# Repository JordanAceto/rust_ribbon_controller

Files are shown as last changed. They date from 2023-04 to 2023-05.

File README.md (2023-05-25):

# Rust Language STM32L412 Ribbon Controller

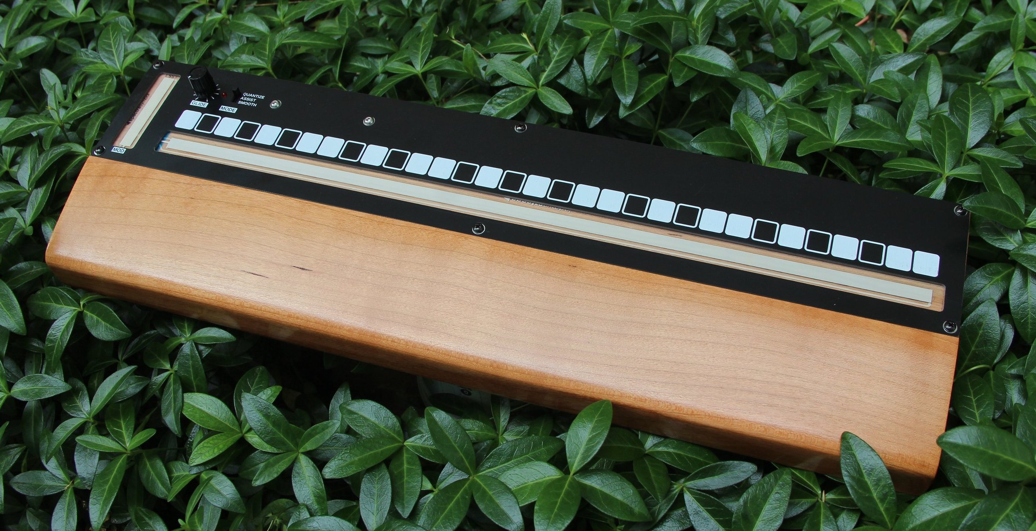
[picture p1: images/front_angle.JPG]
Photo of ribbon controller in nature


## Features

### Three analog outputs
- `RIBBON CV`: 1volt/per octave scaled control voltage generated by the main ribbon
- `GATE`: 5 volt gate signal which is high when pressing the main ribbon and low otherwise
- `MOD CV`: mod-wheel like control voltage generated by the MOD ribbon, in `[0v, +5v]` 

### MIDI output
- Note on/off based on finger position on the ribbon
- Pitch-bend message bends the pitch when the ribbon is in between notes 
- Mod: mod-wheel message generated by the MOD ribbon

### Three pitch modes are available
1) `QUANTIZE`: notes are forced to be musical half steps, sliding around will zipper to new notes
2) `ASSIST`: when you first press a new note it is forced to be a musical half step, but continued sliding is smooth
3) `SMOOTH`: no quantization is performed, offers the greatest degree of pitch freedom but is difficult to play in tune

### Glide control
- Adds portamento to the `RIBBON CV` signal
- This allows you to smooth out the steps when in `QUANTIZE` mode

### Notes about the MIDI output
- This software assumes that the pitch bend range on the receiving instrument is set to +/- 2 semitones (this is typically the default)
    - If the Assist or Smooth modes seem crazy, make sure that the pitch bend range on your instrument is set to +/- 2 semitones
- The MIDI output signal sends note-on, note-off, and pitch bend messages to generate the smooth ribbon action
    - This works best with a mono instrument, and may act differently depending on the MIDI implementation of the receiving device
    - If the receiving instrument has non-retriggering envelopes, it will smoothly slide as expected
    - If the instrument has retriggering envelopes, each time you slide into a new note the envelopes will be triggered
- The MIDI output starts on a fairly low note
    - It works best if the instrument being controlled can be transposed to different octaves

### Rear panel IO jacks and controls
- Output jacks for analog signals `RIBBON CV`, `MOD CV`, and `GATE`
- Standard `MIDI OUT` 5 pin DIN output jack
- `MIDI CH` channel select rotary switch
    - MIDI output is sent on the channel set here
- `9VDC IN` power supply input jack

rear panel render

## Calibration
- A trim potentiometer is exposed through a small hole so the device may be calibrated without disassembly
- Measure the `RIBBON CV` signal with a multimeter
- Set the `MODE` switch to `QUANTIZE`
- Adjust the trim potentiometer while playing alternating octaves so that the octaves are as close to 1.000v apart as you can get
- The `MOD CV` and MIDI output do not require calibration

## Power supply
- A common guitar-pedal style center-negative 9 volt DC wall wart powers the device
- The circuit consumes approximately 20mA from the 9 volt DC power supply

## Project status
- A prototype has been built and tested
- A handmade wooden body houses the components and provides a comfortable wrist rest while playing

## Project goals
- Mostly just for fun and to explore embedded Rust
- Serve as a test bed for the [Josh Ox Ribbon Synth](https://github.com/JordanAceto/josh_Ox_ribbon_synth)
- Build a cute little CV and MIDI source

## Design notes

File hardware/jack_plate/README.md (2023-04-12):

# jack_plate

## ribbon_controller_jack_plate

PCB front
PCB back

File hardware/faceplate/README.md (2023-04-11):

# faceplate

## ribbon_controller_faceplate

PCB front
PCB back

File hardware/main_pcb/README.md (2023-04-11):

# main_pcb

## ribbon_controller

PCB front
PCB back

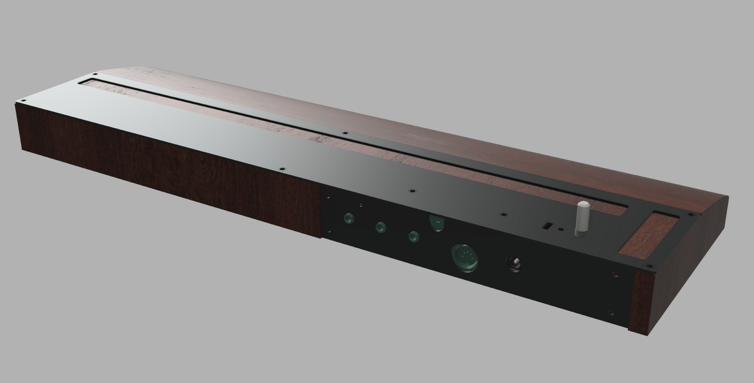
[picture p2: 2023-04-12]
images/rear_angle_render.png

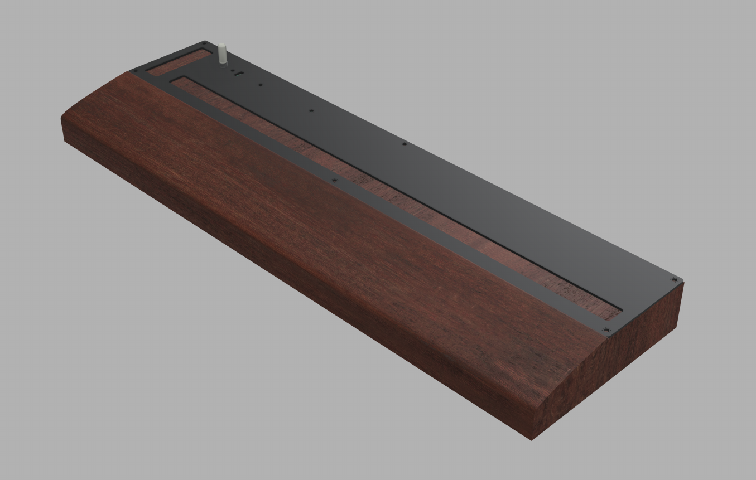
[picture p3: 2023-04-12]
images/front_angle_render.png

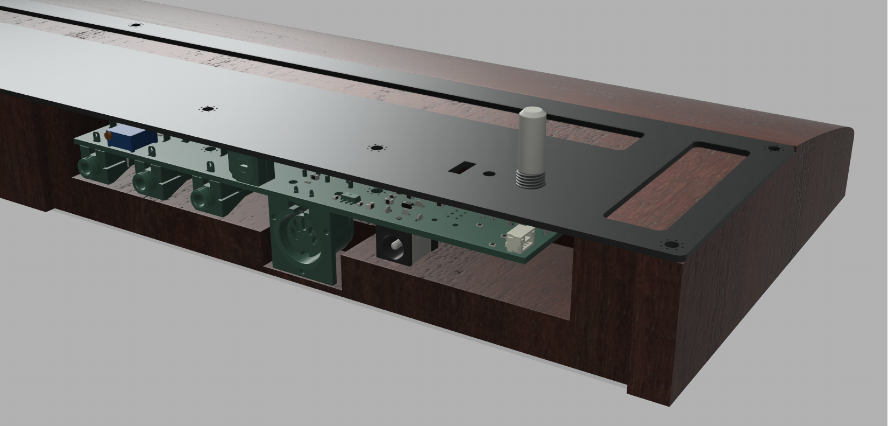
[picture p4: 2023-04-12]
images/pcb_detail_render.png

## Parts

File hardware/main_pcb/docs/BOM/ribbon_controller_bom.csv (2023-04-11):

# | Reference | Qty | Value | Footprint | DNP
1 | C201, C301, C307, C309, C311, C312, C501, C502, C503, C504, C505, C506, C507, C602, C603, C605 | 16 | 100n | Capacitor_SMD:C_0603_1608Metric
2 | C302, C304 | 2 | 4p3 | Capacitor_SMD:C_0603_1608Metric
3 | C303 | 1 | 10u | Capacitor_SMD:C_0805_2012Metric
4 | C305, C306, C308, C310 | 4 | 1u | Capacitor_SMD:C_0805_2012Metric
5 | C601, C604 | 2 | 2u2 | Capacitor_SMD:C_0805_2012Metric
6 | D601 | 1 | XLMDK65D | LED_THT:LED_D3.0mm
7 | D602 | 1 | B5819W | Diode_SMD:D_SOD-123
8 | FB501, FB502 | 2 | 600R @ 100MHz | Inductor_SMD:L_0805_2012Metric
9 | FB601, FB602, FB603 | 3 | 100R @ 100MHz | Inductor_SMD:L_0805_2012Metric
10 | H601, H602 | 2 | MountingHole_Pad | MountingHole:MountingHole_3.2mm_M3_Pad_Via
11 | J101, J102, J103 | 3 | PJ302M | custom_footprints:PJ302M
12 | J104 | 1 | CUI_SDF-50J | custom_footprints:CUI_SDF-50J
13 | J301 | 1 | SWD_header | Connector_PinHeader_2.54mm:PinHeader_1x04_P2.54mm_Vertical
14 | J601 | 1 | CUI_PJ-063AH | Connector_BarrelJack:BarrelJack_CUI_PJ-063AH_Horizontal
15 | R201, R202, R301, R501, R502, R504, R505, R506, R601 | 9 | 10k | Resistor_SMD:R_0603_1608Metric
16 | R203, R204 | 2 | 1M | Resistor_SMD:R_0603_1608Metric
17 | R302, R507, R510, R511 | 4 | 220 | Resistor_SMD:R_0603_1608Metric
18 | R503 | 1 | 9k1 | Resistor_SMD:R_0603_1608Metric
19 | R508, R509 | 2 | 1k | Resistor_SMD:R_0603_1608Metric
20 | RV301 | 1 | 10k | custom_footprints:Potentiometer_Alpha_RD901F-40-00D_Single_Vertical
21 | RV501 | 1 | 2k | custom_footprints:Potentiometer_Bourns_3296P_Horizontal
22 | SP1 | 1 | 400mm_softpot | Connector_JST:JST_GH_SM03B-GHS-TB_1x03-1MP_P1.25mm_Horizontal
23 | SP2 | 1 | 50mm_softpot | Connector_JST:JST_GH_SM03B-GHS-TB_1x03-1MP_P1.25mm_Horizontal
24 | SW301 | 1 | E-Switch_EG2301 | custom_footprints:E-Switch_EG2301
25 | SW302 | 1 | nidec_SD-1011 | custom_footprints:SD-1011
26 | TP401 | 1 | ~{CLR} | TestPoint:TestPoint_Pad_1.5x1.5mm
27 | TP601 | 1 | GND | TestPoint:TestPoint_Bridge_Pitch7.62mm_Drill1.3mm
28 | U1, U4 | 2 | MCP6002-xSN | Package_SO:SO-8_3.9x4.9mm_P1.27mm
29 | U2 | 1 | STM32L412K8Ux | Package_DFN_QFN:QFN-32-1EP_5x5mm_P0.5mm_EP3.45x3.45mm
30 | U3 | 1 | DAC8162xDGSx | Package_SO:VSSOP-10_3x3mm_P0.5mm
31 | U5, U6 | 2 | SN74LV1T34DBV | Package_TO_SOT_SMD:SOT-23-5
32 | U601 | 1 | L78L05_SOT89 | Package_TO_SOT_SMD:SOT-89-3
33 | U602 | 1 | L78L33_SOT89 | Package_TO_SOT_SMD:SOT-89-3
34 | Y1 | 1 | 32_768KHZ | Crystal:Crystal_SMD_MicroCrystal_CC7V-T1A-2Pin_3.2x1.5mm

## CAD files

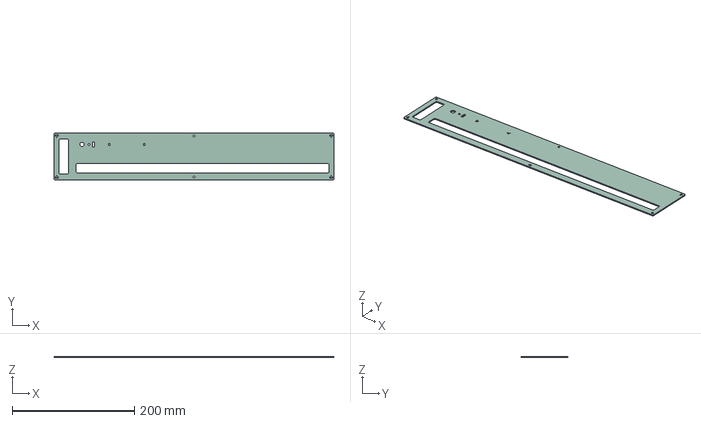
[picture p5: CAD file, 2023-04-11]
hardware/faceplate/docs/3D/ribbon_controller_faceplate.step
457.2 x 76.2 x 1.58 mm

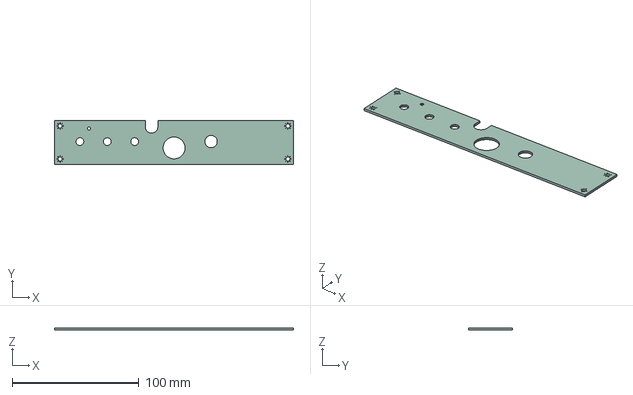
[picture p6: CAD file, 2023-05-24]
hardware/jack_plate/docs/3D/ribbon_controller_jack_plate.step
188.6 x 34.9 x 1.58 mm

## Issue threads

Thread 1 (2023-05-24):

Front panel main ribbon cutout is slightly too long

JordanAceto, 2023-05-24:
The front panel is made of 1.6mm PCB material. There is screen printing to show the notes piano-style, and a cutout so your finger can press on the actual ribbon.

The cutout is just slightly longer than it needs to be. This makes it so if you jam your finger to the very ends, you run off the ribbon and the note you were playing dies or rapidly toggles between on and off.

This isn't a show stopping problem. The user can easily adapt by not moving their finger so far, and it only happens when you play the notes at the extreme ends. But it should be fixed.

The next revision of the front panel should slightly reduce the horizontal span on the main ribbon cutout.

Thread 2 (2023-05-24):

It's hard to cleanly hit the ends of the MODWHEEL ribbon

JordanAceto, 2023-05-24:
When playing the shorter auxiliary MODWHEEL ribbon, it is hard to set your finger on the lowest and highest points and have it stay there. Any slight rolling of your finger bumps the output.

This is mostly noticeable when you have some modulation signal providing vibrato, and you try to turn it all the way down with the MODWHEEL ribbon. It's easy to roll your finger unintentionally and turn the vibrato back on slightly.

To fix, overdrive and clamp the MODWHEEL ribbon so that there are small deadzones at the top and bottom ends. This way, you just need to be near the end, and a small unavoidable finger roll won't throw off the output.

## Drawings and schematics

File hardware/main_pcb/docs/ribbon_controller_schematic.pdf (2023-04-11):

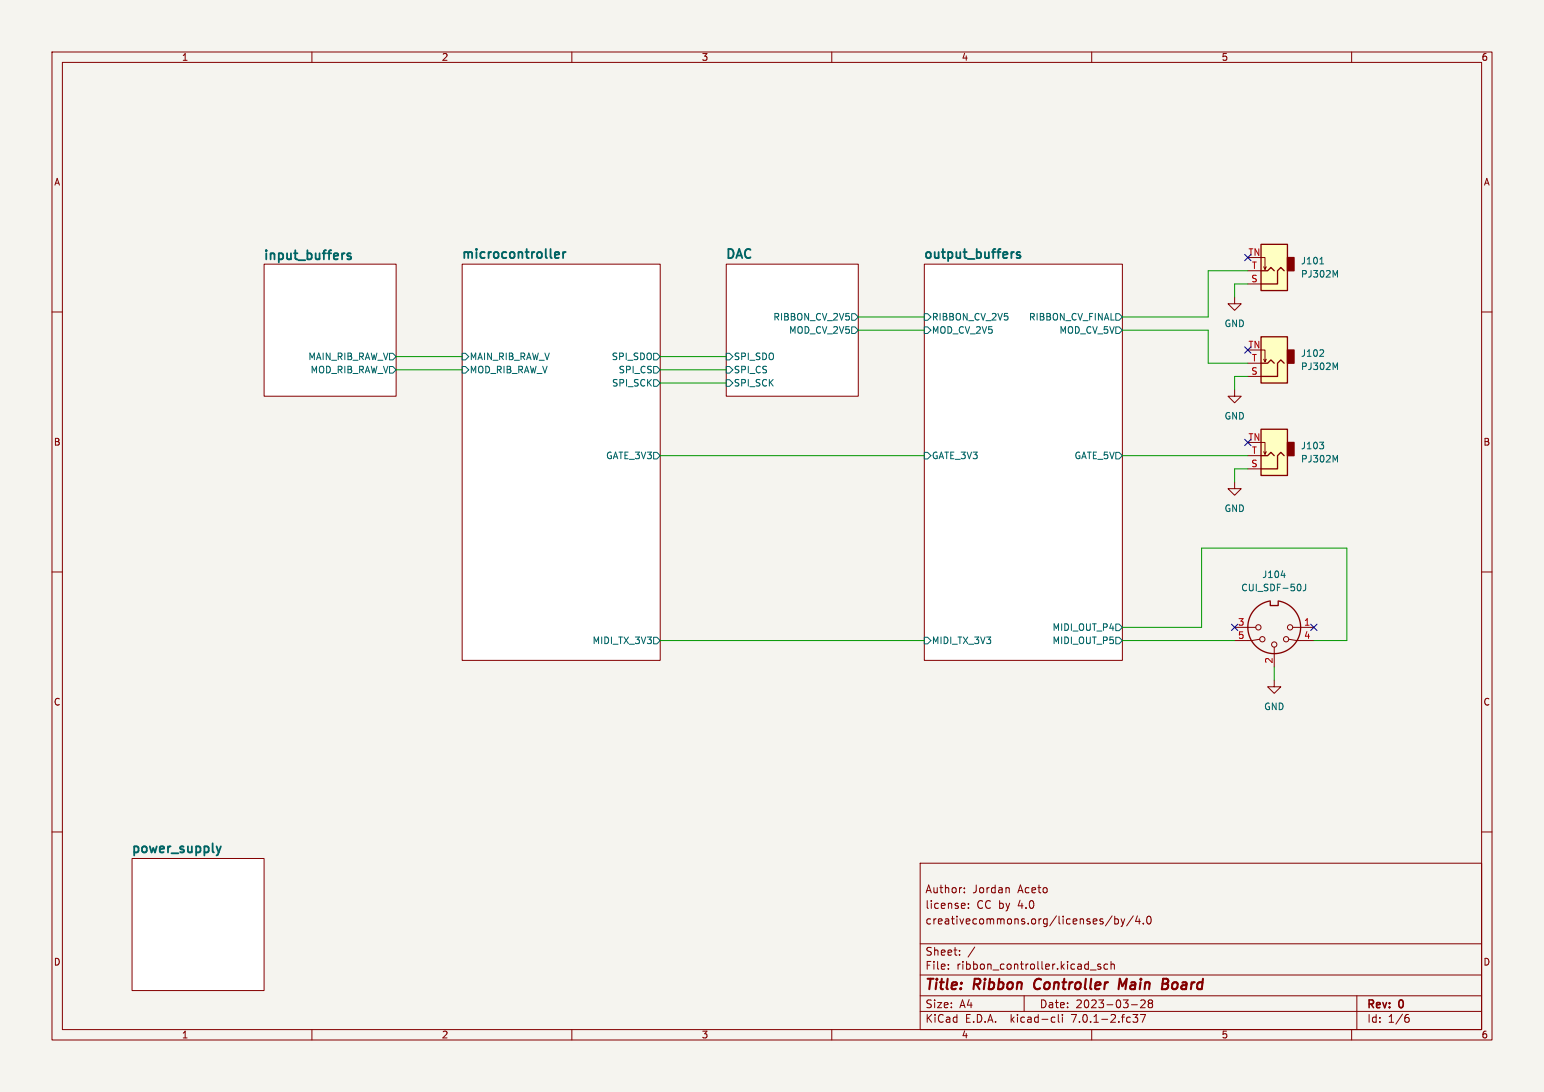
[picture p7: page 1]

File: ribbon_controller.kicad_sch Sheet: / creativecommons.org/licenses/by/4.0

Id: 1/6 Title: Ribbon Controller Main Board

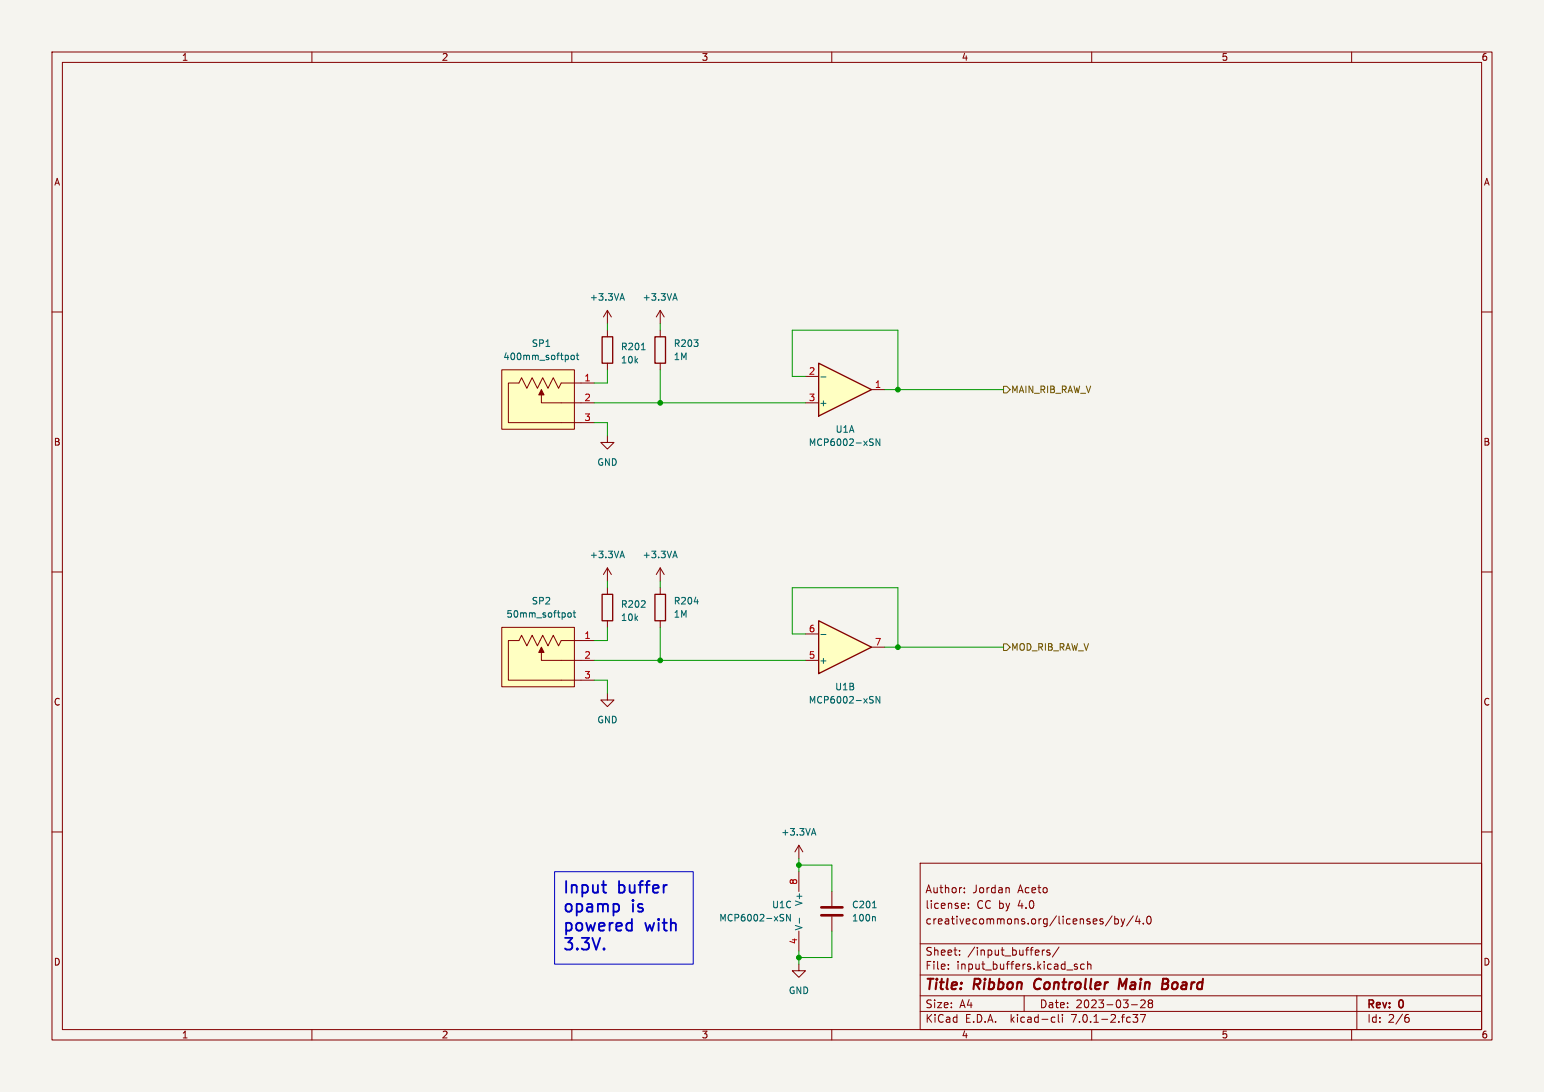
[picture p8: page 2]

creativecommons.org/licenses/by/4.0

File: input_buffers.kicad_sch Sheet: /input_buffers/
Id: 2/6 Title: Ribbon Controller Main Board

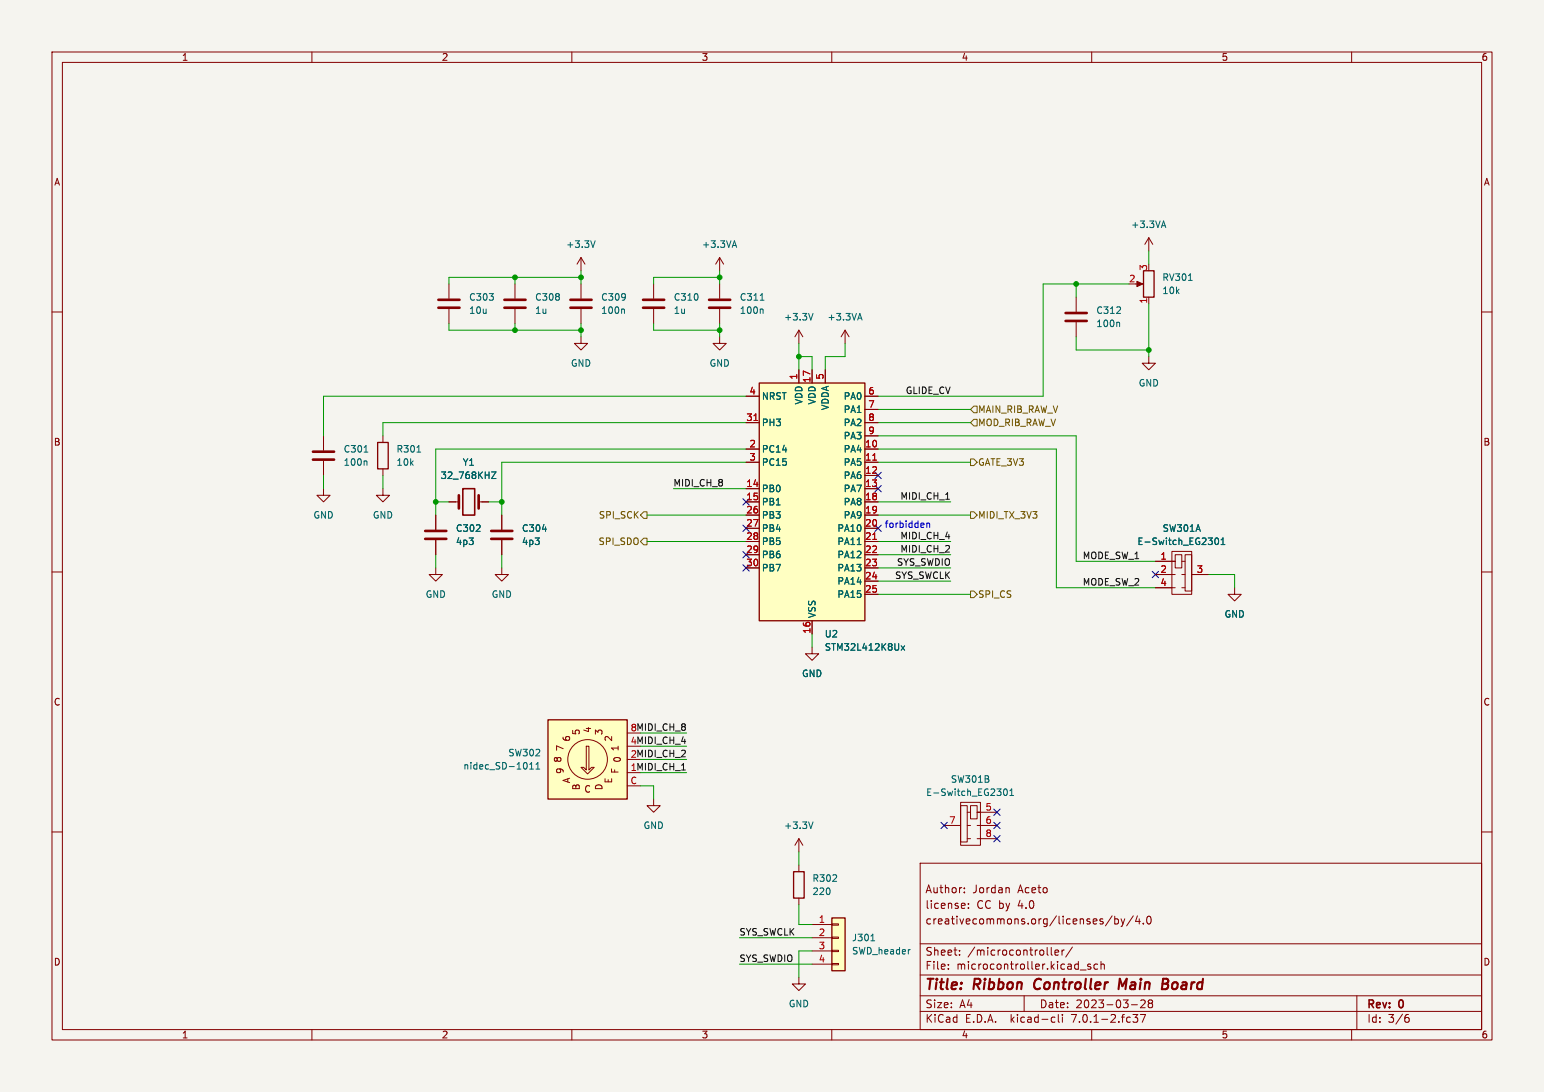
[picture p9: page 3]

1 PA4 10 PA5 11 PA6 12 PA7 13 PB0 14 PB1 15 VSS 16 VDD 17 PA8 18 PA9 19 PC14 2 PA10 20 PA11 21 PA12 22 PA13 23 PA14 24 PA15 25 PB3 26 PB4 27 PB5 28 PB6 29 PC15 3 PB7 30 PH3 31 NRST 4 VDDA

File: microcontroller.kicad_sch Sheet: /microcontroller/ creativecommons.org/licenses/by/4.0

Id: 3/6 Title: Ribbon Controller Main Board

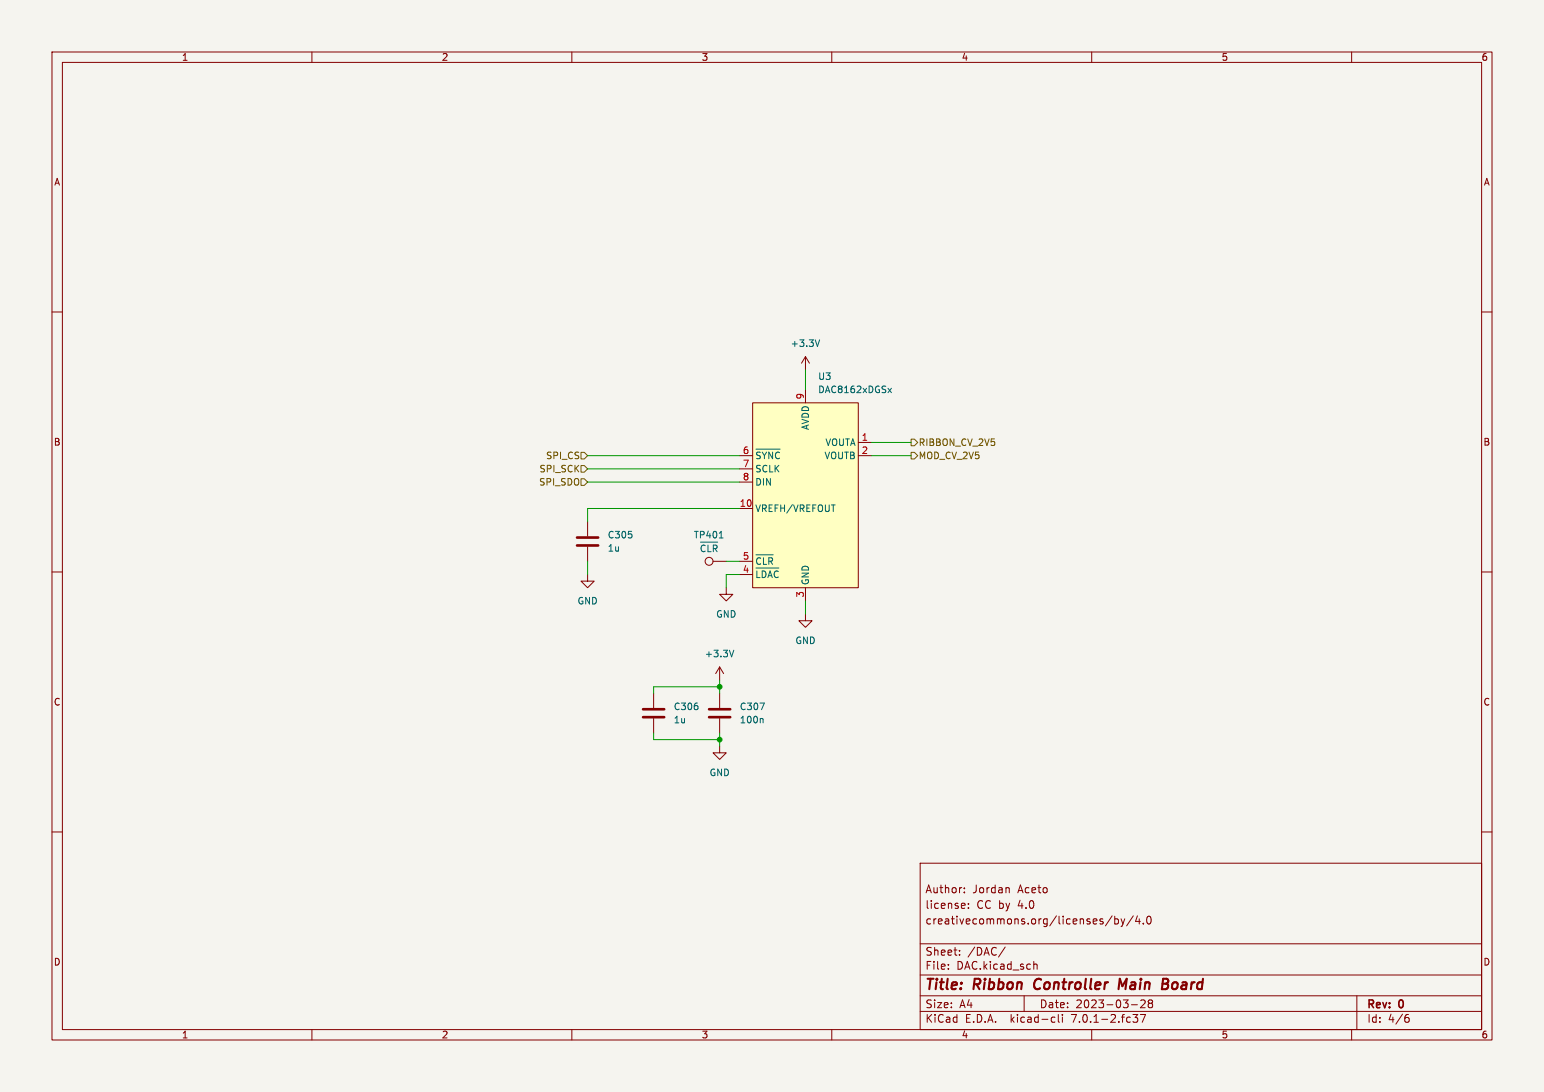
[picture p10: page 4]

3 ~{LDAC} 4 ~{CLR} 5 ~{SYNC} 6 SCLK 7 DIN 8 AVDD

Id: 4/6 Title: Ribbon Controller Main Board

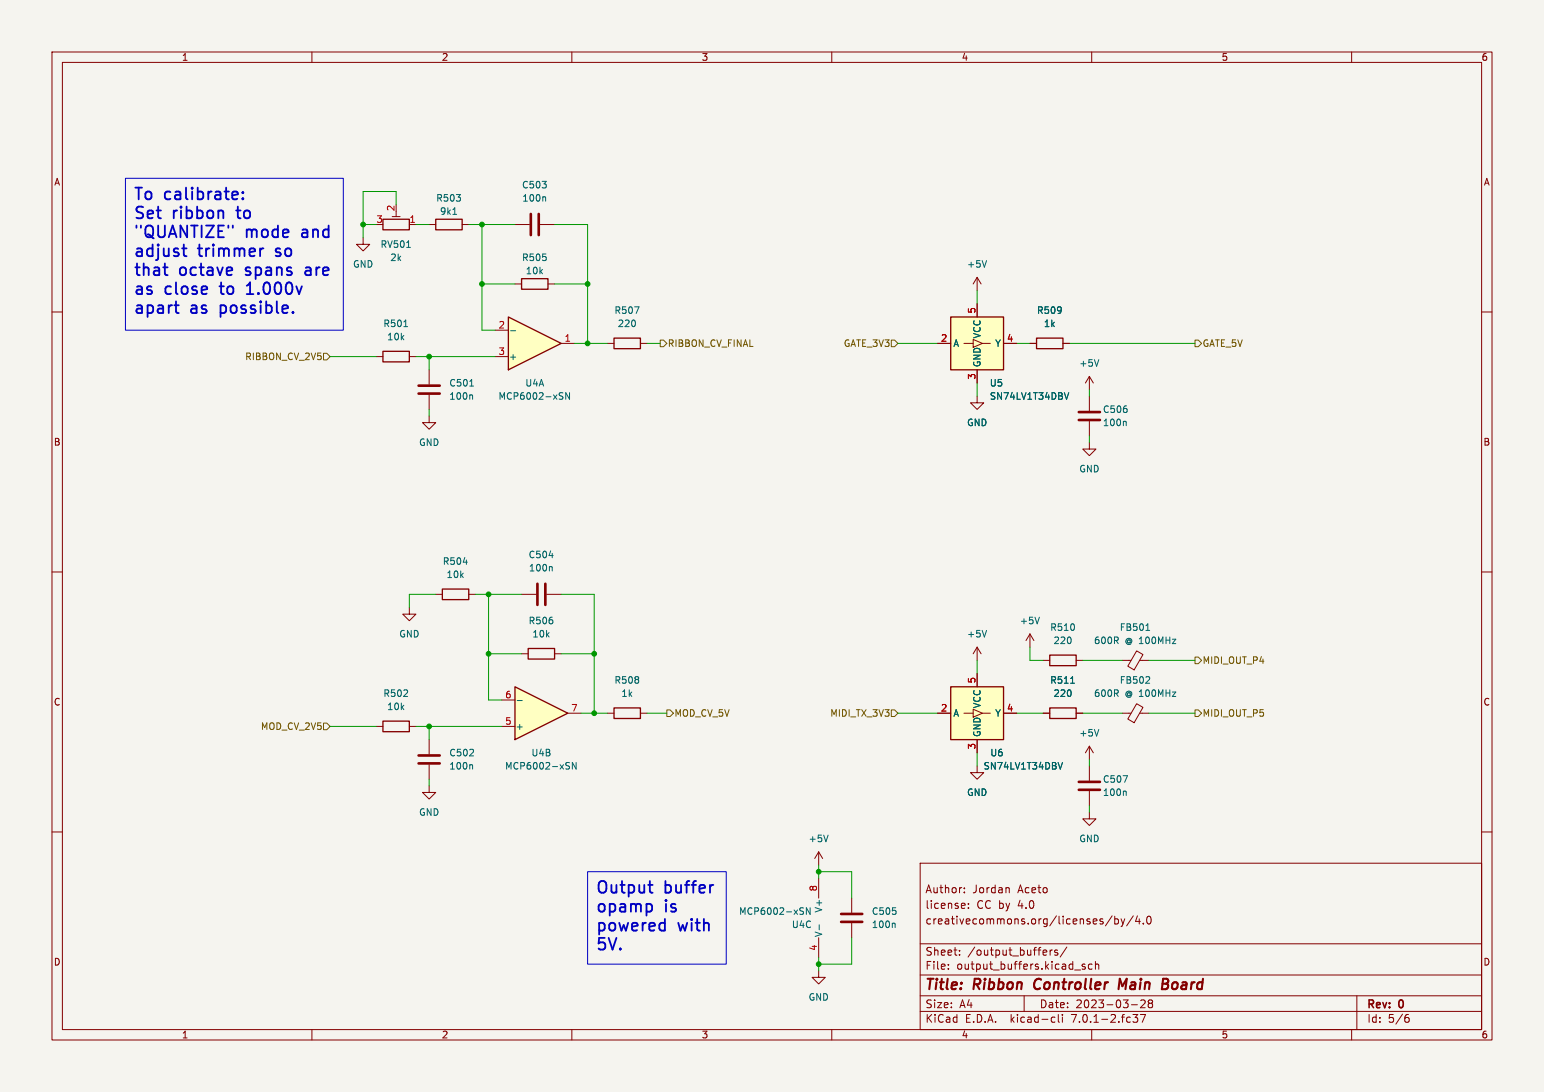
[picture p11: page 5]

To calibrate:
Set ribbon to
"QUANTIZE" mode and
adjust trimmer so
that octave spans are
as close to 1.000v

creativecommons.org/licenses/by/4.0

File: output_buffers.kicad_sch Sheet: /output_buffers/
Id: 5/6 Title: Ribbon Controller Main Board

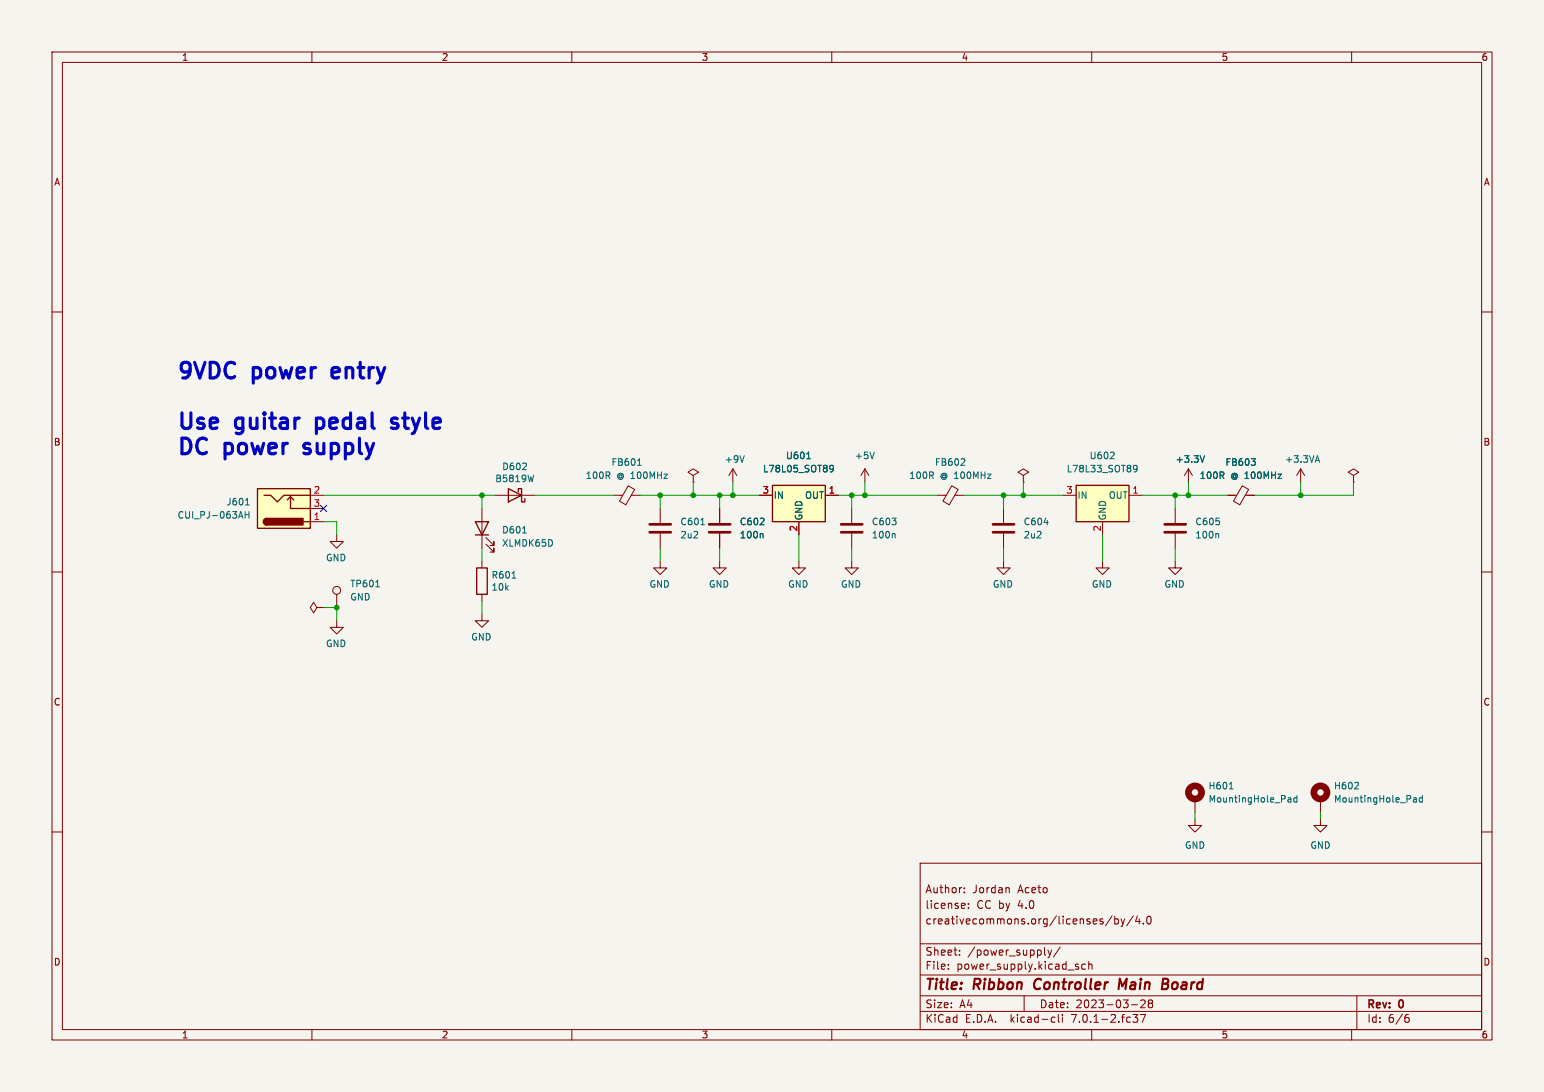
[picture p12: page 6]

creativecommons.org/licenses/by/4.0

Id: 6/6 Title: Ribbon Controller Main Board

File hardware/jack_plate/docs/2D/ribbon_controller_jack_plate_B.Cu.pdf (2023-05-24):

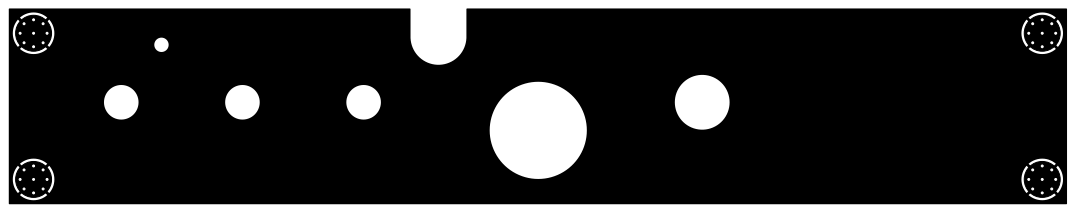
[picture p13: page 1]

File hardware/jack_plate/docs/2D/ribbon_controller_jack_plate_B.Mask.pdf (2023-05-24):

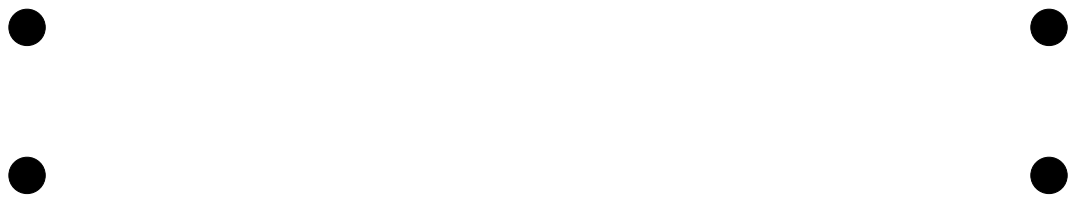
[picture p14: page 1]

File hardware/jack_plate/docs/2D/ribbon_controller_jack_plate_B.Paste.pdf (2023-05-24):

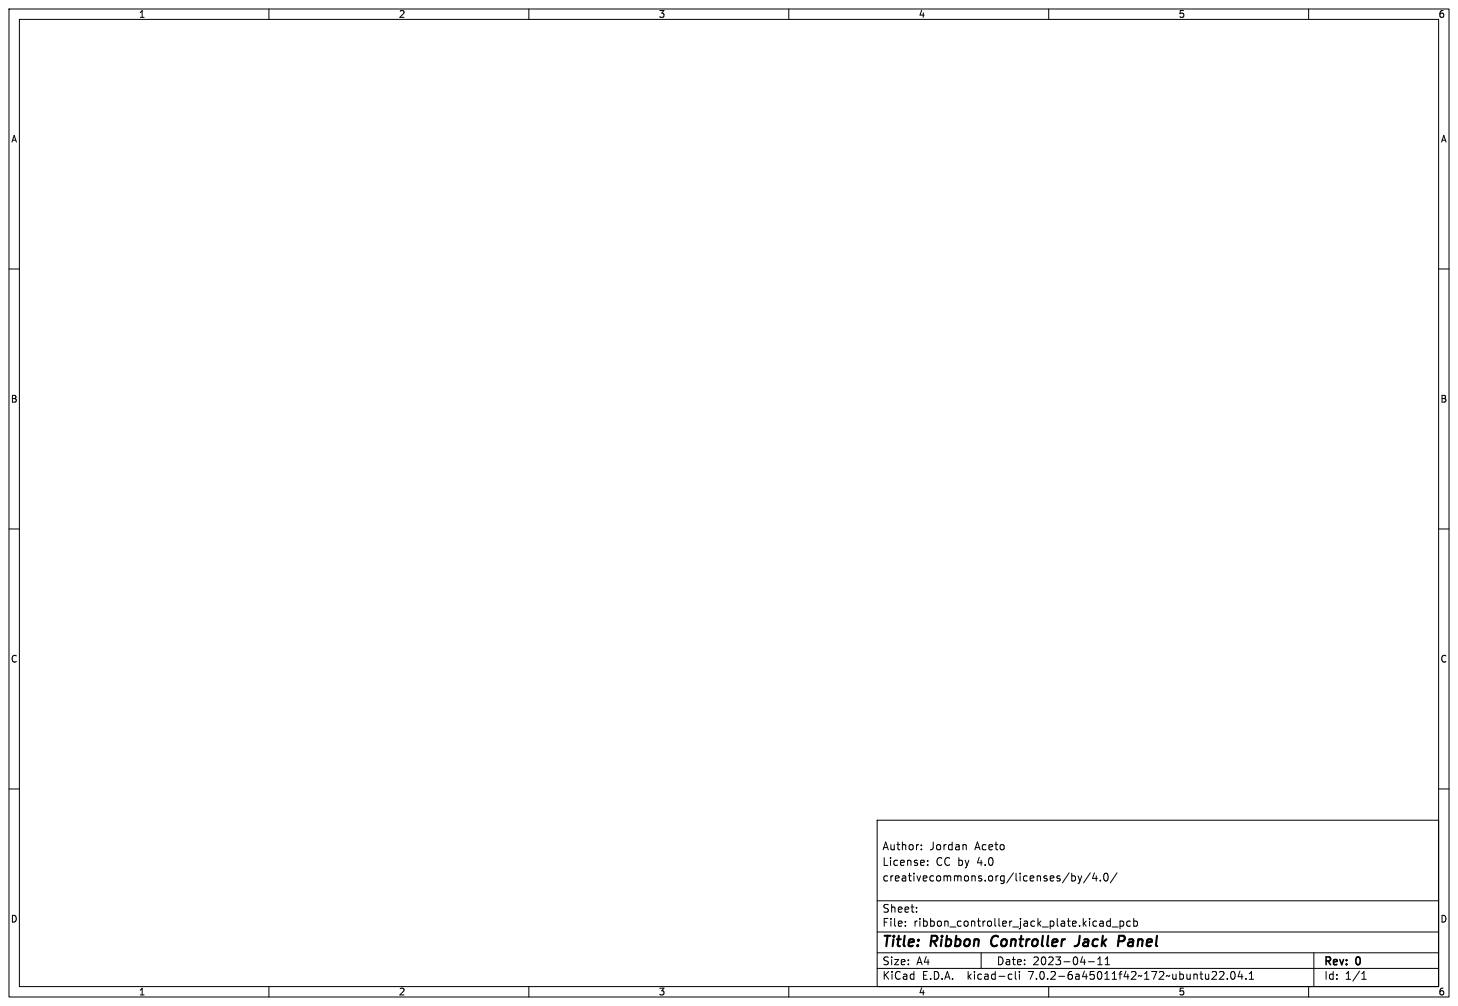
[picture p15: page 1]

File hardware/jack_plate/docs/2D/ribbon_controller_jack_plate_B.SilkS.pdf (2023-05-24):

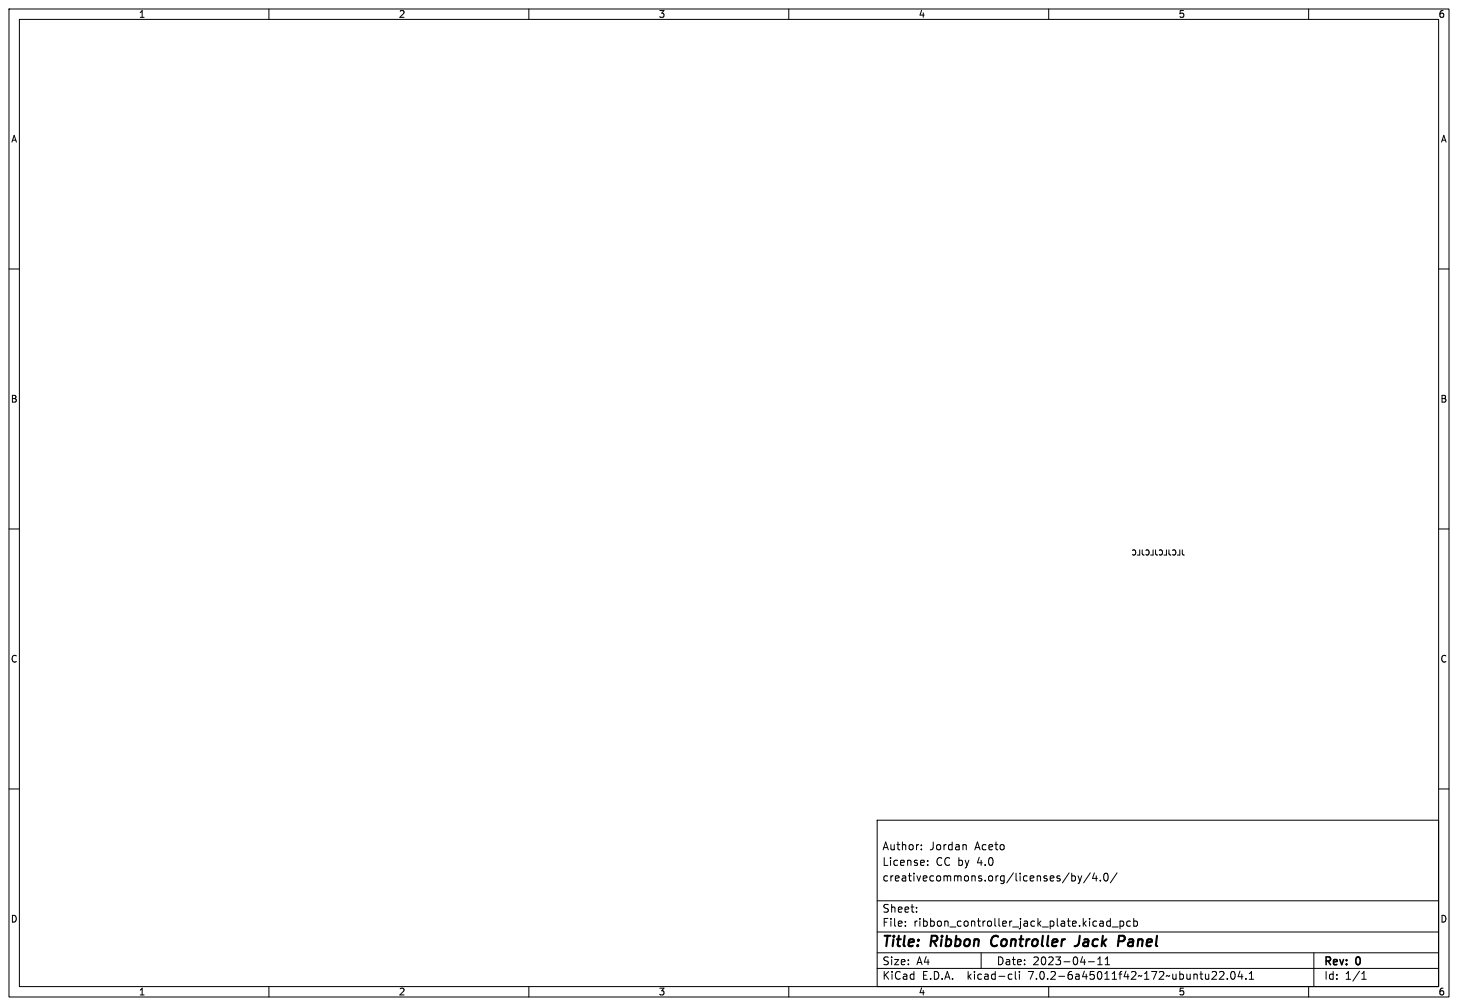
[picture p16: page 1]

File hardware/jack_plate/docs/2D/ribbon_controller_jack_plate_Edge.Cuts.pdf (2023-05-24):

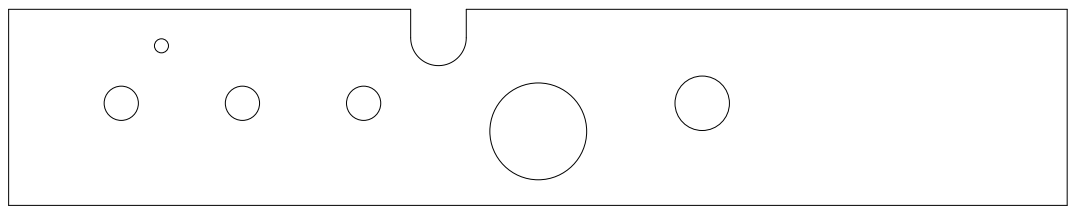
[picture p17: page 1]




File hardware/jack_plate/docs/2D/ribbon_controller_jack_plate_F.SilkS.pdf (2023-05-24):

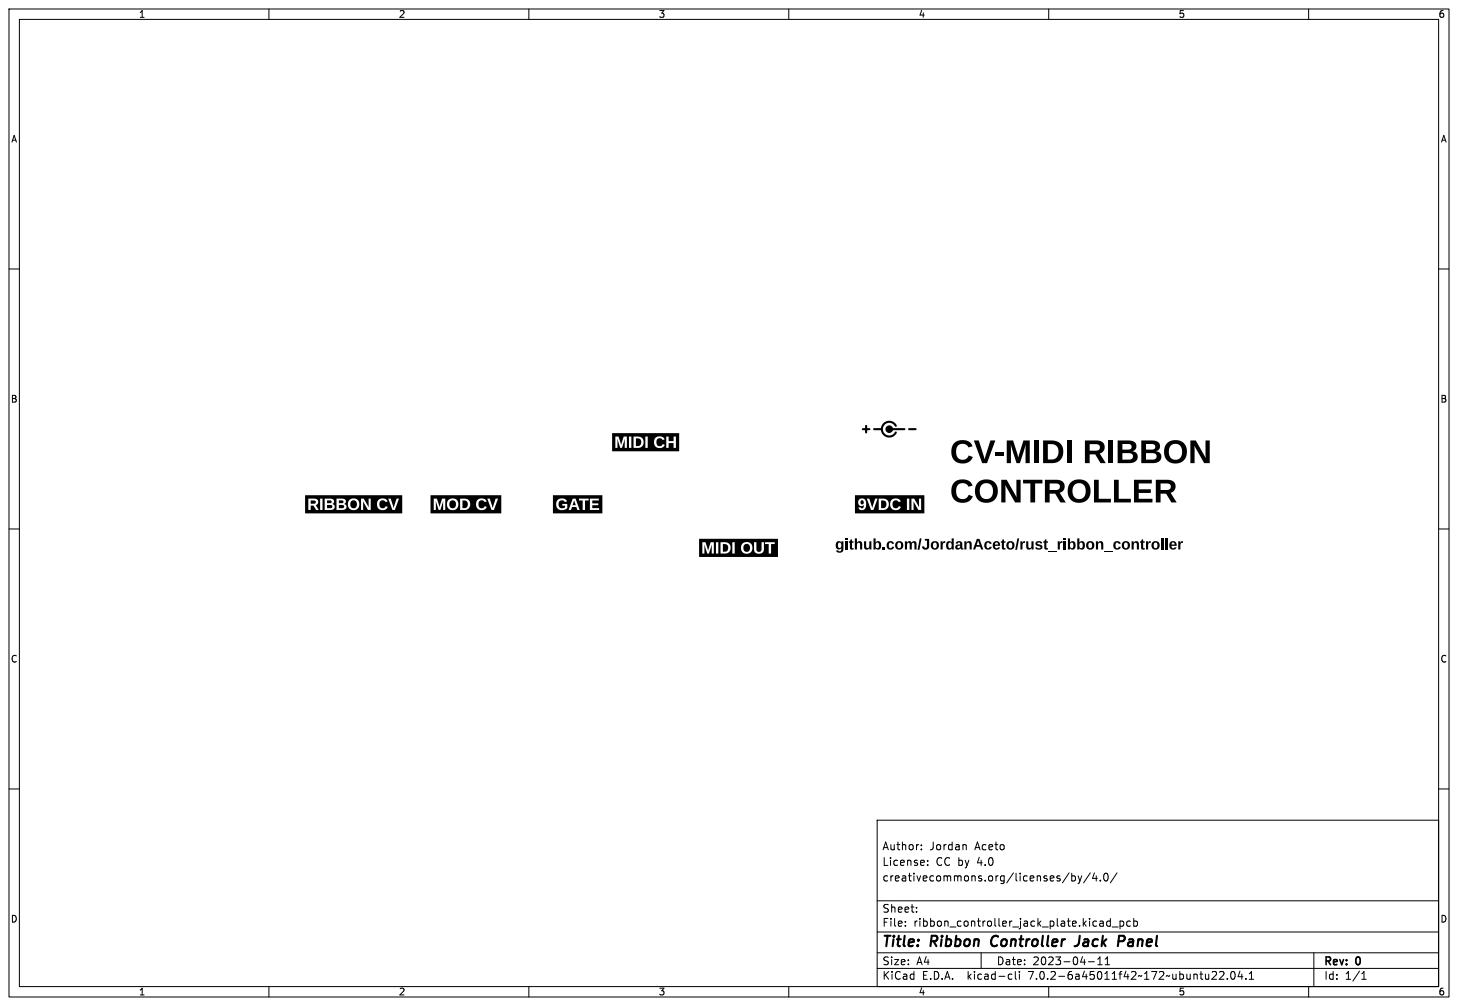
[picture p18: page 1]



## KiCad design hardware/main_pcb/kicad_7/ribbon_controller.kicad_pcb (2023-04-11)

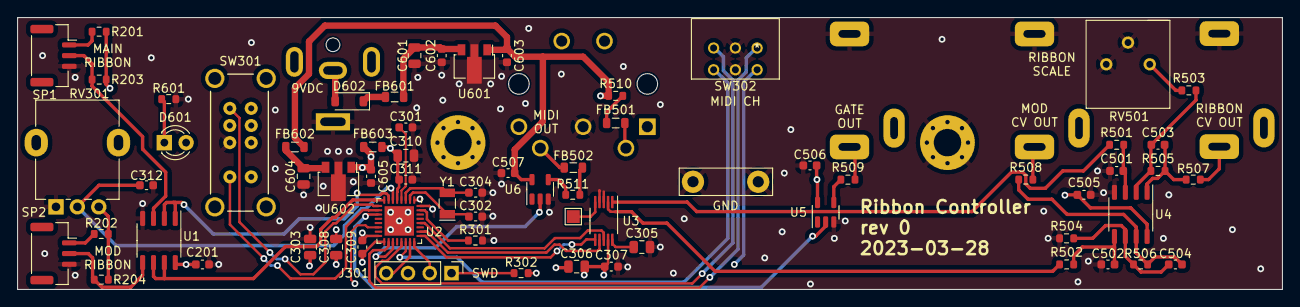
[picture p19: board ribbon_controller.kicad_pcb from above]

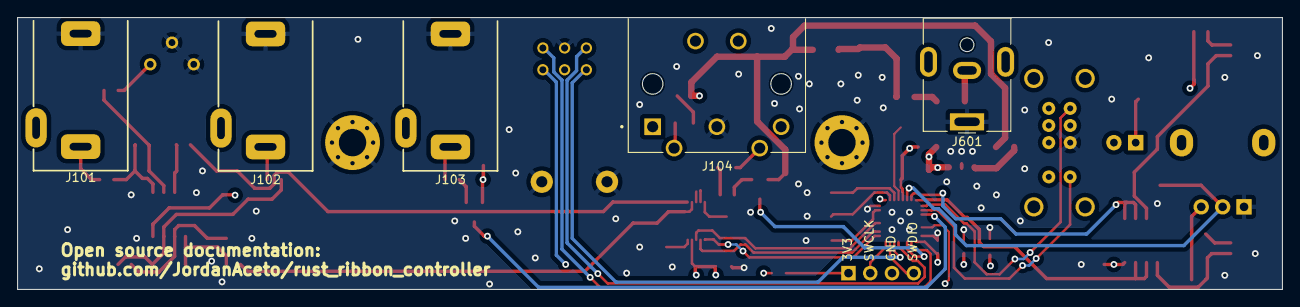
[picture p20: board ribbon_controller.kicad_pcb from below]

Board: 4 copper layers, 147.7 x 31.8 mm, 75 parts (5 on the bottom side), 54 nets.

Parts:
C201, C301, C307, C309, C311, C312, C501, C502, C503, C504, C505, C506, C507, C602, C603, C605: 100n; C_0603_1608Metric
C302, C304: 4p3; C_0603_1608Metric
C303: 10u; C_0805_2012Metric
C305, C306, C308, C310: 1u; C_0805_2012Metric
C601, C604: 2u2; C_0805_2012Metric
D601: XLMDK65D; LED_D3.0mm
D602: B5819W; D_SOD-123
FB501, FB502: 600R @ 100MHz; L_0805_2012Metric
FB601, FB602, FB603: 100R @ 100MHz; L_0805_2012Metric
H601, H602: MountingHole_Pad; MountingHole_3.2mm_M3_Pad_Via
J101, J102, J103: PJ302M
J104: CUI_SDF-50J
J301: SWD_header; PinHeader_1x04_P2.54mm_Vertical
J601: CUI_PJ-063AH; BarrelJack_CUI_PJ-063AH_Horizontal
R201, R202, R301, R501, R502, R504, R505, R506, R601: 10k; R_0603_1608Metric
R203, R204: 1M; R_0603_1608Metric
R302, R507, R510, R511: 220; R_0603_1608Metric
R503: 9k1; R_0603_1608Metric
R508, R509: 1k; R_0603_1608Metric
RV301: 10k; Potentiometer_Alpha_RD901F-40-00D_Single_Vertical
RV501: 2k; Potentiometer_Bourns_3296P_Horizontal
SP1: 400mm_softpot; JST_GH_SM03B-GHS-TB_1x03-1MP_P1.25mm_Horizontal
SP2: 50mm_softpot; JST_GH_SM03B-GHS-TB_1x03-1MP_P1.25mm_Horizontal
SW301: E-Switch_EG2301
SW302: nidec_SD-1011; SD-1011
TP401: ~{CLR}; TestPoint_Pad_1.5x1.5mm
TP601: GND; TestPoint_Bridge_Pitch7.62mm_Drill1.3mm
U1, U4: MCP6002-xSN; SO-8_3.9x4.9mm_P1.27mm
U2: STM32L412K8Ux; QFN-32-1EP_5x5mm_P0.5mm_EP3.45x3.45mm
U3: DAC8162xDGSx; VSSOP-10_3x3mm_P0.5mm
U5, U6: SN74LV1T34DBV; SOT-23-5
U601: L78L05_SOT89; SOT-89-3
U602: L78L33_SOT89; SOT-89-3
Y1: 32_768KHZ; Crystal_SMD_MicroCrystal_CC7V-T1A-2Pin_3.2x1.5mm

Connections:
+3.3V: C303.1, C306.1, C307.1, C308.1, C309.1, C605.1, FB603.1, R302.1, U2.1 (VDD), U2.17 (VDD), U3.9 (AVDD), U602.1 (OUT)
+3.3VA: C201.1, C310.1, C311.1, FB603.2, R201.1, R202.1, R203.1, R204.1, RV301.3, U1.8 (V+), U2.5 (VDDA)
+5V: C505.1, C506.1, C507.1, C603.1, FB602.1, R510.1, U4.8 (V+), U5.5 (VCC), U6.5 (VCC), U601.1 (OUT)
+9V: C601.1, C602.1, FB601.2, U601.3 (IN)
/DAC/MOD_CV_2V5: R502.1, U3.2 (VOUTB)
/DAC/RIBBON_CV_2V5: R501.1, U3.1 (VOUTA)
/DAC/SPI_CS: U2.25 (PA15), U3.6 (~SYNC)
/DAC/SPI_SCK: U2.26 (PB3), U3.7 (SCLK)
/DAC/SPI_SDO: U2.28 (PB5), U3.8 (DIN)
/input_buffers/MAIN_RIB_RAW_V: U1.1, U1.2 (-), U2.7 (PA1)
/input_buffers/MOD_RIB_RAW_V: U1.6 (-), U1.7, U2.8 (PA2)
/microcontroller/GATE_3V3: U2.11 (PA5), U5.2 (A)
/microcontroller/GLIDE_CV: C312.1, RV301.2, U2.6 (PA0)
/microcontroller/MIDI_CH_1: SW302.1, U2.18 (PA8)
/microcontroller/MIDI_CH_2: SW302.2, U2.22 (PA12)
/microcontroller/MIDI_CH_4: SW302.4, U2.21 (PA11)
/microcontroller/MIDI_CH_8: SW302.8, U2.14 (PB0)
/microcontroller/MIDI_TX_3V3: U2.19 (PA9), U6.2 (A)
/microcontroller/MODE_SW_1: SW301.1, U2.9 (PA3)
/microcontroller/MODE_SW_2: SW301.4, U2.10 (PA4)
/microcontroller/SYS_SWCLK: J301.2, U2.24 (PA14)
/microcontroller/SYS_SWDIO: J301.4, U2.23 (PA13)
/output_buffers/GATE_5V: J103.T, R509.2
/output_buffers/MIDI_OUT_P4: FB501.2, J104.4
/output_buffers/MIDI_OUT_P5: FB502.2, J104.5
/output_buffers/MOD_CV_5V: J102.T, R508.2
/output_buffers/RIBBON_CV_FINAL: J101.T, R507.2
GND: C201.2, C301.1, C302.1, C303.2, C304.1, C305.2, C306.2, C307.2, C308.2, C309.2, C310.2, C311.2, C312.2, C501.1, C502.1, C505.2, C506.2, C507.2, C601.2, C602.2, C603.2, C604.2, C605.2, H601.1, H602.1, J101.S, J102.S, J103.S, J104.2, J301.3, J601.1, R301.1, R504.1, R601.1, RV301.1, RV501.2, RV501.3, SP1.3, SP2.3, SW301.3, SW302.C, TP601.1, U1.4 (V-), U2.16 (VSS), U2.32 (VSS), U2.33 (VSS), U3.3 (GND), U3.4 (~LDAC), U4.4 (V-), U5.3 (GND), U6.3 (GND), U601.2 (GND), U602.2 (GND)
unnamed: C503.2, R505.2, R507.1, U4.1
unnamed: C504.2, R506.2, R508.1, U4.7
unnamed: D601.2 (A), D602.2 (A), J601.2
unnamed: D601.1 (K), R601.2
unnamed: D602.1 (K), FB601.1
unnamed: FB501.1, R510.2
unnamed: FB502.1, R511.2
unnamed: J301.1, R302.2
unnamed: R201.2, SP1.1
unnamed: R202.2, SP2.1
unnamed: R503.1, RV501.1
unnamed: R203.2, SP1.2, U1.3 (+)
unnamed: R204.2, SP2.2, U1.5 (+)
unnamed: C301.2, U2.4 (NRST)
unnamed: C302.2, U2.2 (PC14), Y1.1
unnamed: C304.2, U2.3 (PC15), Y1.2
unnamed: R301.2, U2.31 (PH3)
unnamed: C305.1, U3.10 (VREFH/VREFOUT)
unnamed: TP401.1, U3.5 (~CLR)
unnamed: C501.2, R501.2, U4.3 (+)
unnamed: C503.1, R503.2, R505.1, U4.2 (-)
unnamed: C502.2, R502.2, U4.5 (+)
unnamed: C504.1, R504.2, R506.1, U4.6 (-)
unnamed: R509.1, U5.4 (Y)
unnamed: R511.1, U6.4 (Y)
unnamed: C604.1, FB602.2, U602.3 (IN)

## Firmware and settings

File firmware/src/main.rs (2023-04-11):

#![no_std]
#![no_main]

mod board;
mod midi_transmitter;
mod ui;

use synth_utils::{glide_processor, quantizer, ribbon_controller};

use crate::{
    board::{AdcPin, Board, Dac8162Channel},
    ui::{PitchMode, UiState},
};

use midi_convert::midi_types::MidiMessage;

use panic_halt as _;

use cortex_m_rt::entry;

const FAST_RIBBON_SAMPLE_RATE: u32 = board::TIM2_FREQ_HZ;
const OUTPUT_UPDATE_SAMPLE_RATE: u32 = board::TIM15_FREQ_HZ;

const MAIN_RIBBON_PIN: AdcPin = AdcPin::PA1;
const MOD_RIBBON_PIN: AdcPin = AdcPin::PA2;

const RIBBON_BUFF_CAPACITY: usize =
    ribbon_controller::sample_rate_to_capacity(FAST_RIBBON_SAMPLE_RATE);

// about 2 1/2 octaves of range, lowest note is F and highest note is C
const MAIN_RIBBON_NUM_SEMITONES: f32 = 32.0_f32;
const MAIN_RIBBON_MAX_VOUT: f32 = MAIN_RIBBON_NUM_SEMITONES / 12.0_f32;
const LOWEST_MIDI_NOTE: u8 = 5;

const MIDI_CC_MOD_WHEEL: u8 = 0x01;

#[entry]
fn main() -> ! {
    let mut board = Board::init();
    let mut ui = UiState::new();

    // main ribbon for playing notes
    let mut main_ribbon = ribbon_controller::RibbonController::<RIBBON_BUFF_CAPACITY>::new(
        FAST_RIBBON_SAMPLE_RATE as f32,
        19_876.0_f32, // end-to-end resistance of the softpot as measured
        10_000.0_f32, // resistance of the series resistor going to vref
        1E6,          // pullup resistor from the wiper to the positive voltage refererence
    );

    // smaller aux ribbon which acts like a mod-wheel
    let mut mod_ribbon = ribbon_controller::RibbonController::<RIBBON_BUFF_CAPACITY>::new(
        FAST_RIBBON_SAMPLE_RATE as f32,
        10_271.0_f32, // end-to-end resistance of the softpot as measured
        10_000.0_f32, // resistance of the series resistor going to vref
        1E6,          // pullup resistor from the wiper to the positive voltage refererence
    );

    // quantizer for converting the raw ribbon reading to 1v/oct analog steps
    let mut ribbon_quantizer = quantizer::Quantizer::new();
    // second quantizer for re-converting prior to calculating midi note and pitch bend
    let mut midi_quantizer = quantizer::Quantizer::new();

    let mut glide = glide_processor::GlideProcessor::new(OUTPUT_UPDATE_SAMPLE_RATE as f32);

    // used in ASSIST pitch mode
    let mut offset_when_finger_pressed_down: f32 = 0.0_f32;

    let mut midi = midi_transmitter::MidiTransmitter::new();
    // keep track of conversions so we don't write mode MIDI data than needed if nothing changed
    let mut last_midi_note_sent = 0;
    let mut last_pitch_bend = 0.0_f32;
    let mut last_mod_wheel = 0;

    // small delay to allow the ribbon voltage to settle before beginning
    board.delay_ms(100);

    ui.update(&mut board);

    loop {
        // slow timer for updating UI, reading pots and such
        if board.get_tim6_timeout() {
            ui.update(&mut board);
            glide.set_time(ui.glide_time());
        }

        // fast timer for polling the ribbon
        if board.get_tim2_timeout() {
            main_ribbon.poll(board.read_adc(MAIN_RIBBON_PIN));
            mod_ribbon.poll(board.read_adc(MOD_RIBBON_PIN));
        }

        // timer to update analog and MIDI outputs
        if board.get_tim15_timeout() {
            // expand the ribbon signal to 1volt/octave range
            let mut one_v_per_oct_ribbon = ribbon_to_dac8162_1v_per_oct(main_ribbon.value());

            let quantized_ribbon = ribbon_quantizer.convert(one_v_per_oct_ribbon);

            let finger_just_pressed = main_ribbon.finger_just_pressed();
            let finger_just_released = main_ribbon.finger_just_released();

            let pitch_mode = ui.pitch_mode();

            // the main ribbon can be one of three modes
            match pitch_mode {
                // hard-quantize and smooth modes are simple to calculate
                PitchMode::HardQuantize => {
                    one_v_per_oct_ribbon = quantized_ribbon.stairstep;
                }
                PitchMode::Smooth => {
                    let fudge_factor = quantizer::HALF_SEMITONE_WIDTH;
                    one_v_per_oct_ribbon -= fudge_factor;
                }
                // assist mode has more going on
                PitchMode::Assist => {
                    if finger_just_pressed {
                        // When the user first presses down after having lifted their finger record the offset between the
                        // finger position and the center of the note. We'll use this offset to make sure that it plays
                        // a nice in-tune note at first-press.
                        offset_when_finger_pressed_down = quantized_ribbon.fraction;

                        // use the stairstep for the first press for a nice in-tune note
                        one_v_per_oct_ribbon = quantized_ribbon.stairstep;
                    } else {
                        // The user is continuing to press the ribbon and maybe sliding around, use the smooth val but
                        // remove the offset
                        one_v_per_oct_ribbon -= offset_when_finger_pressed_down;
                    }
                }
            };

            let ribbon_with_portamento = glide.process(one_v_per_oct_ribbon);

            // set the analog outputs
            board.dac8162_set_vout(ribbon_with_portamento, Dac8162Channel::A);

            // scale the mod wheel ribbon for 5v range
            board.dac8162_set_vout(
                mod_ribbon.value() * board::DAC8162_MAX_VOUT,
                Dac8162Channel::B,
            );
            board.set_gate(main_ribbon.finger_is_pressing());

            // the extra quarter step helps keep things in-tune
            let midi_conversion =
                midi_quantizer.convert(one_v_per_oct_ribbon + quantizer::HALF_SEMITONE_WIDTH);
            let this_midi_note = midi_conversion.note_num + LOWEST_MIDI_NOTE;
            // MIDI pitch bend is usually set to 2 semitones, the extra divide-by-two avoids overshooting
            let this_pitch_bend = midi_conversion.fraction / (quantizer::SEMITONE_WIDTH * 2.0_f32);

            let midi_channel = board.read_midi_ch_switch();

            // Each round there may be zero or more MIDI messages sent:
            //
            // * a note-on message if the user just pressed the ribbon or if they slid into a new note
            // * one or two note-off messages if the user just released the ribbon or if they slid into a new note
            // * a pitch bend message if the user is pressing the ribbon and the value has changed since last time
            if finger_just_pressed {
                midi.push(MidiMessage::NoteOn(
                    midi_channel.into(),
                    this_midi_note.into(),
                    127.into(),
                ));
            } else if main_ribbon.finger_is_pressing() && this_midi_note != last_midi_note_sent {
                midi.push(MidiMessage::NoteOn(
                    midi_channel.into(),
                    this_midi_note.into(),
                    127.into(),
                ));

                midi.push(MidiMessage::NoteOff(
                    midi_channel.into(),
                    last_midi_note_sent.into(),
                    0.into(),
                ));
            } else if finger_just_released {
                midi.push(MidiMessage::NoteOff(
                    midi_channel.into(),
                    this_midi_note.into(),
                    0.into(),
                ));
                if this_midi_note != last_midi_note_sent {
                    midi.push(MidiMessage::NoteOff(
                        midi_channel.into(),
                        last_midi_note_sent.into(),
                        0.into(),
                    ));
                }
            }
            last_midi_note_sent = this_midi_note;

            if last_pitch_bend != this_pitch_bend {
                midi.push(MidiMessage::PitchBendChange(
                    midi_channel.into(),
                    this_pitch_bend.into(),
                ));
                last_pitch_bend = this_pitch_bend;
            }

            let this_mod_wheel = (mod_ribbon.value() * 127.0_f32) as u8;
            if this_mod_wheel != last_mod_wheel {
                midi.push(MidiMessage::ControlChange(
                    midi_channel.into(),
                    MIDI_CC_MOD_WHEEL.into(),
                    this_mod_wheel.into(),
                ));
                last_mod_wheel = this_mod_wheel;
            }

            // send any MIDI messages, the queue might be empty but that is fine
            midi.send_queue(&mut board);
        }
    }
}

/// `ribbon_to_dac8164_1v_per_oct(r)` is the ribbon value in `[0.0, 1.0]` scaled to 1 volt per octave
fn ribbon_to_dac8162_1v_per_oct(ribb: f32) -> f32 {
    ribb * MAIN_RIBBON_MAX_VOUT
}

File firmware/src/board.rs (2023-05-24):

use stm32l4xx_hal::{
    adc::{SampleTime, Sequence, ADC},
    delay::Delay,
    device::SPI1,
    gpio::{Alternate, Input, Output, Pin, PullUp, PushPull, H8, L8},
    hal::spi::{Mode, Phase, Polarity},
    pac::{ADC1, DMA1, TIM15, TIM2, TIM6, USART1},
    prelude::*,
    rcc::{ClockSecuritySystem, CrystalBypass},
    serial,
    spi::Spi,
    timer::Timer,
};

// type aliases for complex types so clippy doesn't complain, pins are as required by the physical PCB layout
type MidiChannelSwitch = (
    Pin<Input<PullUp>, H8, 'A', 8>,  // 1s
    Pin<Input<PullUp>, H8, 'A', 12>, // 2s
    Pin<Input<PullUp>, H8, 'A', 11>, // 4s
    Pin<Input<PullUp>, L8, 'B', 0>,  // 8s
);
type SpiBus = Spi<
    SPI1,
    (
        Pin<Alternate<PushPull, 5>, L8, 'B', 3>,
        Pin<Alternate<PushPull, 5>, L8, 'B', 4>,
        Pin<Alternate<PushPull, 5>, L8, 'B', 5>,
    ),
>;

/// The physical board structure is represented here
pub struct Board {
    // USART for MIDI
    _midi_tx: serial::Tx<USART1>,
    _midi_rx: serial::Rx<USART1>,

    // SPI for DAC
    spi: SpiBus,
    nss: Pin<Output<PushPull>, H8, 'A', 15>, // manual chip select

    // general purpose delay
    delay: Delay,

    // 2 pins for the 3-position QUANTIZE MODE switch
    mode_switch: (
        Pin<Input<PullUp>, L8, 'A', 3>,
        Pin<Input<PullUp>, L8, 'A', 4>,
    ),

    // 4 pins for the rotary MIDI channel select switch
    midi_ch_switch: MidiChannelSwitch,

    // ribbon gate output
    gate_pin: Pin<Output<PushPull>, L8, 'A', 5>,
}

impl Board {
    /// `Board::init()` is the board structure with all peripherals initialized.
    pub fn init() -> Self {
        ////////////////////////////////////////////////////////////////////////
        //
        // general peripheral housekeeping, core peripherals and clocks
        //
        ////////////////////////////////////////////////////////////////////////
        let cp = cortex_m::Peripherals::take().unwrap();
        let dp = stm32l4xx_hal::pac::Peripherals::take().unwrap();
        let mut flash = dp.FLASH.constrain();
        let mut rcc = dp.RCC.constrain();
        let mut pwr = dp.PWR.constrain(&mut rcc.apb1r1);

        let clocks = rcc
            .cfgr
            .lse(CrystalBypass::Disable, ClockSecuritySystem::Disable) // LSE auto trims the HSI
            .sysclk(SYST_CLK_FREQ_MHZ.MHz())
            .pclk1(SYST_CLK_FREQ_MHZ.MHz())
            .pclk2(SYST_CLK_FREQ_MHZ.MHz())
            .freeze(&mut flash.acr, &mut pwr);

        let mut gpioa = dp.GPIOA.split(&mut rcc.ahb2);
        let mut gpiob = dp.GPIOB.split(&mut rcc.ahb2);

        let dma_channels = dp.DMA1.split(&mut rcc.ahb1);

        let mut delay = Delay::new(cp.SYST, clocks);

        ////////////////////////////////////////////////////////////////////////
        //
        // Gate pin
        //
        ////////////////////////////////////////////////////////////////////////
        let gate_pin = gpioa.pa5.into_push_pull_output_in_state(
            &mut gpioa.moder,
            &mut gpioa.otyper,
            PinState::Low,
        );

        ////////////////////////////////////////////////////////////////////////
        //
        // ADC
        //
        ////////////////////////////////////////////////////////////////////////

        // configure DMA1 to transfer ADC readings to the buffer
        let mut dma1_ch1 = dma_channels.1;
        unsafe {
            dma1_ch1.set_peripheral_address(&dp.ADC1.dr as *const _ as u32, false);
            dma1_ch1.set_memory_address(ADC_DMA_BUFF.as_ptr() as u32, true);
        }
        dma1_ch1.set_transfer_length(NUM_ADC_DMA_SIGNALS as u16);
        unsafe {
            (*DMA1::ptr()).ccr1.modify(|_, w| {
                w.msize()
                    .bits16()
                    .psize()
                    .bits16()
                    .minc()
                    .enabled()
                    .circ()
                    .enabled()
                    .en()
                    .set_bit()
            });
        }

        // configure the ADC
        let mut adc1 = ADC::new(
            dp.ADC1,
            dp.ADC_COMMON,
            &mut rcc.ahb2,
            &mut rcc.ccipr,
            &mut delay,
        );

        // gpio pins which are configured as analog inputs on the physical PCB
        let mut adc_pins = (
            gpioa.pa0.into_analog(&mut gpioa.moder, &mut gpioa.pupdr),
            gpioa.pa1.into_analog(&mut gpioa.moder, &mut gpioa.pupdr),
            gpioa.pa2.into_analog(&mut gpioa.moder, &mut gpioa.pupdr),
        );
        adc1.configure_sequence(&mut adc_pins.0, Sequence::One, SampleTime::Cycles640_5);
        adc1.configure_sequence(&mut adc_pins.1, Sequence::Two, SampleTime::Cycles640_5);
        adc1.configure_sequence(&mut adc_pins.2, Sequence::Three, SampleTime::Cycles640_5);

        unsafe {
            // configure hardware oversampler for 16 bit resolution
            (*ADC1::ptr()).cfgr2.modify(|_, w| {
                w.ovss()
                    .bits(0b0001) // shift right by 1
                    .ovsr()
                    .bits(0b100) // oversample 32x
                    .rovse()
                    .set_bit()
            });
            // enable continuous DMA mode
            (*ADC1::ptr())
                .cfgr
                .modify(|_, w| w.dmacfg().set_bit().dmaen().set_bit().cont().set_bit());
        }

        dma1_ch1.start();
        adc1.start_conversion();

        ////////////////////////////////////////////////////////////////////////
        //
        // TIMx periodic timers
        //
        ////////////////////////////////////////////////////////////////////////
        let _tim2 = Timer::tim2(dp.TIM2, TIM2_FREQ_HZ.Hz(), clocks, &mut rcc.apb1r1);

        let _tim6 = Timer::tim6(dp.TIM6, TIM6_FREQ_HZ.Hz(), clocks, &mut rcc.apb1r1);

        let _tim15 = Timer::tim15(dp.TIM15, TIM15_FREQ_HZ.Hz(), clocks, &mut rcc.apb2);

        ////////////////////////////////////////////////////////////////////////
        //
        // USART
        //
        ////////////////////////////////////////////////////////////////////////

        // configure DMA1 to transmit bytes via the UART
        let mut dma1_ch4 = dma_channels.4;
        unsafe {
            dma1_ch4.set_peripheral_address(&dp.USART1.tdr as *const _ as u32, false);
            dma1_ch4.set_memory_address(MIDI_USART_DMA_BUFF.as_ptr() as u32, true);
        }
        unsafe {
            (*DMA1::ptr()).ccr4.modify(|_, w| {
                w.pl()
                    .high()
                    .msize()
                    .bits8()
                    .psize()
                    .bits8()
                    .minc()
                    .enabled()
                    .dir()
                    .from_memory()
            });
            // map DMA channel 4 to UART tx
            (*DMA1::ptr()).cselr.modify(|_, w| w.c4s().bits(0b0010));
        }
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

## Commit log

2022-12-22 Enable ADC hardware oversampling for 16 bit resolution
2022-12-25 Add SPI DAC
2023-02-12 Ignore kicad backup folders
2023-02-12 Add kicad7 files so we can tweak the schematic snippet with new changes
    [rust_ribbon_ctl_snippet.kicad_pcb, rust_ribbon_ctl_snippet.kicad_sch]
2023-02-14 Add mode switch with 3 MIDI note modes
    [rust_ribbon_ctl_snippet.kicad_sch]
2023-02-14 Remove old testing comments, add function docstrings for board switch fcs
2023-04-11 Massive project overhaul, use STM32L412 uC, fab circuit boards
    [DAC.kicad_sch, input_buffers.kicad_sch, microcontroller.kicad_sch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]
2023-04-11 Add MIDI mod-wheel code
2023-04-12 Design jack plate
    [ribbon_controller_jack_plate.kicad_pcb, ribbon_controller_jack_plate.step]
2023-04-15 Add measured current draw to README
2023-04-15 Tweak SPI DAC so that Vref turns on reliably
2023-05-24 Move JLC placeholder text silkscreen out of mounting hole
    [ribbon_controller_jack_plate.kicad_pcb, ribbon_controller_jack_plate.step]
2023-05-24 Add photo of finished device, rename images, update main README

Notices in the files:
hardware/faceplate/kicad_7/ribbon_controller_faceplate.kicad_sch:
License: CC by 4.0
